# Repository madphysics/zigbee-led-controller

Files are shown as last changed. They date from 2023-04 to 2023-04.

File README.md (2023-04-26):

View this project on [CADLAB.io](https://cadlab.io/project/26827). 

# Zigbee LED Controller

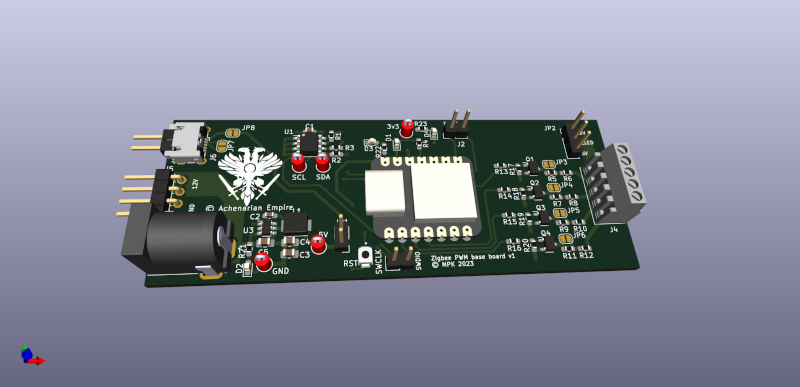
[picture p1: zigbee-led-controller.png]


A simple carrier card for driving some LEDs via PWM. Hosts an off the ZigBee module.

* Runs from 5V
* Derives 3v3 from 5V
* Has optional 12V rail for the PWM
* 4 channel, RGB+W low-side PWM

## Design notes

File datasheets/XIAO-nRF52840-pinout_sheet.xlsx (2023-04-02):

Pin | Name | Function | Description | Recommended usage | Seeed Studio XIAO nRF52840 pin definitions and functions |  |  |  | BOOT
A8 | P0.31 AIN7 | Digital I/O Analog input | General purpose I/O Analog input | Standard drive, low frequency I/O only |  |  |  |  | JTAG/SWD
A10 | P0.29 AIN5 | Digital I/O Analog input | General purpose I/O Analog input | Standard drive, low frequency I/O only | A3 | D3 |  |  | UART
A12 | P0.02 AIN0 | Digital I/O Analog input | General purpose I/O Analog input | Standard drive, low frequency I/O only | A0 | D0 |  |  | SPI
A14 | P1.15 | Digital I/O | General purpose I/O | Standard drive, low frequency I/O only |  | D10 | MOSI |  | ALL PWM
A16 | P1.13 | Digital I/O | General purpose I/O | Standard drive, low frequency I/O only |  | D8 | SCK |  | USB
A18 | DEC2 | Power | 1.3 V regulator supply decoupling |  |  |  |  |  | Analog
A20 | P1.10 | Digital I/O | General purpose I/O | Standard drive, low frequency I/O only |  |  |  |  | IIC
A22 | VDD | Power | Power supply |  |  |  |  |  | Digital
A23 | XC2 | Analog input | Connection for 32 MHz crystal |  |  |  |  |  | GPIO
B1 | VDD | Power | Power supply |  |  |  |  |  | QTouch
B3 | DCC | Power | DC/DC converter output |  |  |  |  |  | LED
B5 | DEC4 | Power | 1.3 V regulator supply decoupling | Must be connected to DEC6 (pin E24)
B7 | VSS | Power | Ground
B9 | P0.30 AIN6 | Digital I/O Analog input | General purpose I/O Analog input | Standard drive, low frequency I/O only |  | D13 | LED_GREEN
B11 | P0.28 AIN4 | Digital I/O Analog input | General purpose I/O Analog input | Standard drive, low frequency I/O only | A2 | D2
B13 | P0.03 | Digital I/O Analog input | General purpose I/O | Standard drive, low frequency I/O only | A1 | D1
B15 | P1.14 | Digital I/O | General purpose I/O | Standard drive, low frequency I/O only |  | D9 | MISO
B17 | P1.12 | Digital I/O | General purpose I/O | Standard drive, low frequency I/O only |  | D7 | PIN_SERIAL1_RX
B19 | P1.11 | Digital I/O | General purpose I/O | Standard drive, low frequency I/O only |  | D6 | PIN_SERIAL1_TX
B24 | XC1 | Analog input | Connection for 32 MHz crystal
C1 | DEC1 | Power | 1.1 V regulator supply decoupling
D2 | P0.00 XL1 | Digital I/O Analog input | General purpose I/O Connection for 32.768 kHz crystal
D23 | DEC3 | Power | Power supply, decoupling
E24 | DEC6 | Power | 1.3 V regulator supply decoupling | Must be connected to DEC4 (pin B5)
F2 | P0.01 XL2 | Digital I/O Analog input | General purpose I/O Connection for 32.768 kHz crystal
F23 | VSS_PA | Power | Ground (radio supply)
G1 | P0.26 | Digital I/O | General purpose I/O |  |  | D11 | LED_BUILTIN | LED_RED
H2 | P0.27 | Digital I/O | General purpose I/O
H23 | ANT | RF | Single-ended radio antenna connection | See Reference circuitry on page 588 for guidelines on how to ensure good RF performance
J1 | P0.04 AIN2 | Digital I/O Analog input | General purpose I/O Analog input |  | A4 | D4 | SDA
J24 | P0.10 NFC2 | Digital I/O NFC input | General purpose I/O NFC antenna connection | Standard drive, low frequency I/O only |  | D31 | NFC2 | VBAT
K2 | P0.05 AIN3 | Digital I/O Analog input | General purpose I/O Analog input |  | A5 | D5 | SCL
L1 | P0.06 | Digital I/O | General purpose I/O |  |  | D12 | LED_BLUE
L24 | P0.09 NFC1 | Digital I/O NFC input | General purpose I/O NFC antenna connection only | Standard drive, low frequency I/O only |  | D30 | NFC1
M2 | P0.07 TRACECLK | Digital I/O Trace clock | General purpose I/O Trace buffer clock
N1 | P0.08 | Digital I/O | General purpose I/O
N24 | DEC5 Not connected | Power | 1.3 V regulator supply decoupling for build codes Dxx and earlier. Not connected for build codes Fxx and later.
P2 | P1.08 | Digital I/O | General purpose I/O
P23 | P1.07 | Digital I/O | General purpose I/O | Standard drive, low frequency I/O only
R1 | P1.09 TRACEDATA3 | Digital I/O Trace data | General purpose I/O Trace buffer TRACEDATA[3]
R24 | P1.06 | Digital I/O | General purpose I/O | Standard drive, low frequency I/O only
T2 | P0.11 TRACEDATA2 | Digital I/O Trace data | General purpose I/O Trace buffer TRACEDATA[2]
T23 | P1.05 | Digital I/O | General purpose I/O | Standard drive, low frequency I/O only
U1 | P0.12 TRACEDATA1 | Digital I/O Trace data | General purpose I/O Trace buffer TRACEDATA[1]
U24 | P1.04 | Digital I/O | General purpose I/O | Standard drive, low frequency I/O only
V23 | P1.03 | Digital I/O | General purpose I/O | Standard drive, low frequency I/O only
W1 | VDD | Power | Power supply
W24 | P1.02 | Digital I/O | General purpose I/O | Standard drive, low frequency I/O only
Y2 | VDDH | Power | High voltage power supply
Y23 | P1.01 | Digital I/O | General purpose I/O | Standard drive, low frequency I/O only
AA24 | SWDCLK | Debug | Serial wire debug clock input for debug and programming
AB2 | DCCH | Power | DC/DC converter output
AC5 | DECUSB | Power | USB 3.3 V regulator supply decoupling
AC9 | P0.14 | Digital I/O | General purpose I/O |  |  | D14 | READ_BAT
AC11 | P0.16 | Digital I/O | General purpose I/O
AC13 | P0.18 nRESET | Digital I/O | General purpose I/O Configurable as pin RESET | QSPI/CSN
AC15 | P0.19 | Digital I/O | General purpose I/O | QSPI/SCK
AC17 | P0.21 | Digital I/O | General purpose I/O | QSPI |  | D24 | QSPI_SCK
AC19 | P0.23 | Digital I/O | General purpose I/O | QSPI |  | D29 | QSPI_SIO_3 HOLD
AC21 | P0.25 | Digital I/O | General purpose I/O |  |  | D25 | QSPI_CSN
AC24 | SWDIO | Debug | Serial wire debug I/O for debug and programming
AD2 | VBUS | Power | 5 V input for USB 3.3 V regulator
AD4 | D- | USB | USB D-
AD6 | D+ | USB | USB D+
AD8 | P0.13 | Digital I/O | General purpose I/O |  |  | D22 | BQ25100 HICHG
AD10 | P0.15 | Digital I/O | General purpose I/O
AD12 | P0.17 | Digital I/O | General purpose I/O |  |  | D23 | BQ25100 ~CHG
AD14 | VDD | Power | Power supply
AD16 | P0.20 | Digital I/O | General purpose I/O |  |  | D26 | QSPI_SIO_0 DI
AD18 | P0.22 | Digital I/O | General purpose I/O | QSPI |  | D28 | QSPI_SIO_2 WP
AD20 | P0.24 | Digital I/O | General purpose I/O |  |  | D27 | QSPI_SIO_1 DO
AD22 | P1.00 TRACEDATA0 | Digital I/O Trace data | General purpose I/O Trace buffer TRACEDATA[0] Serial wire output (SWO) | QSPI
AD23 | VDD | Power | Power supply
Die pad | VSS | Power | Ground pad | Exposed die pad must be connected to ground (VSS) for proper device operation

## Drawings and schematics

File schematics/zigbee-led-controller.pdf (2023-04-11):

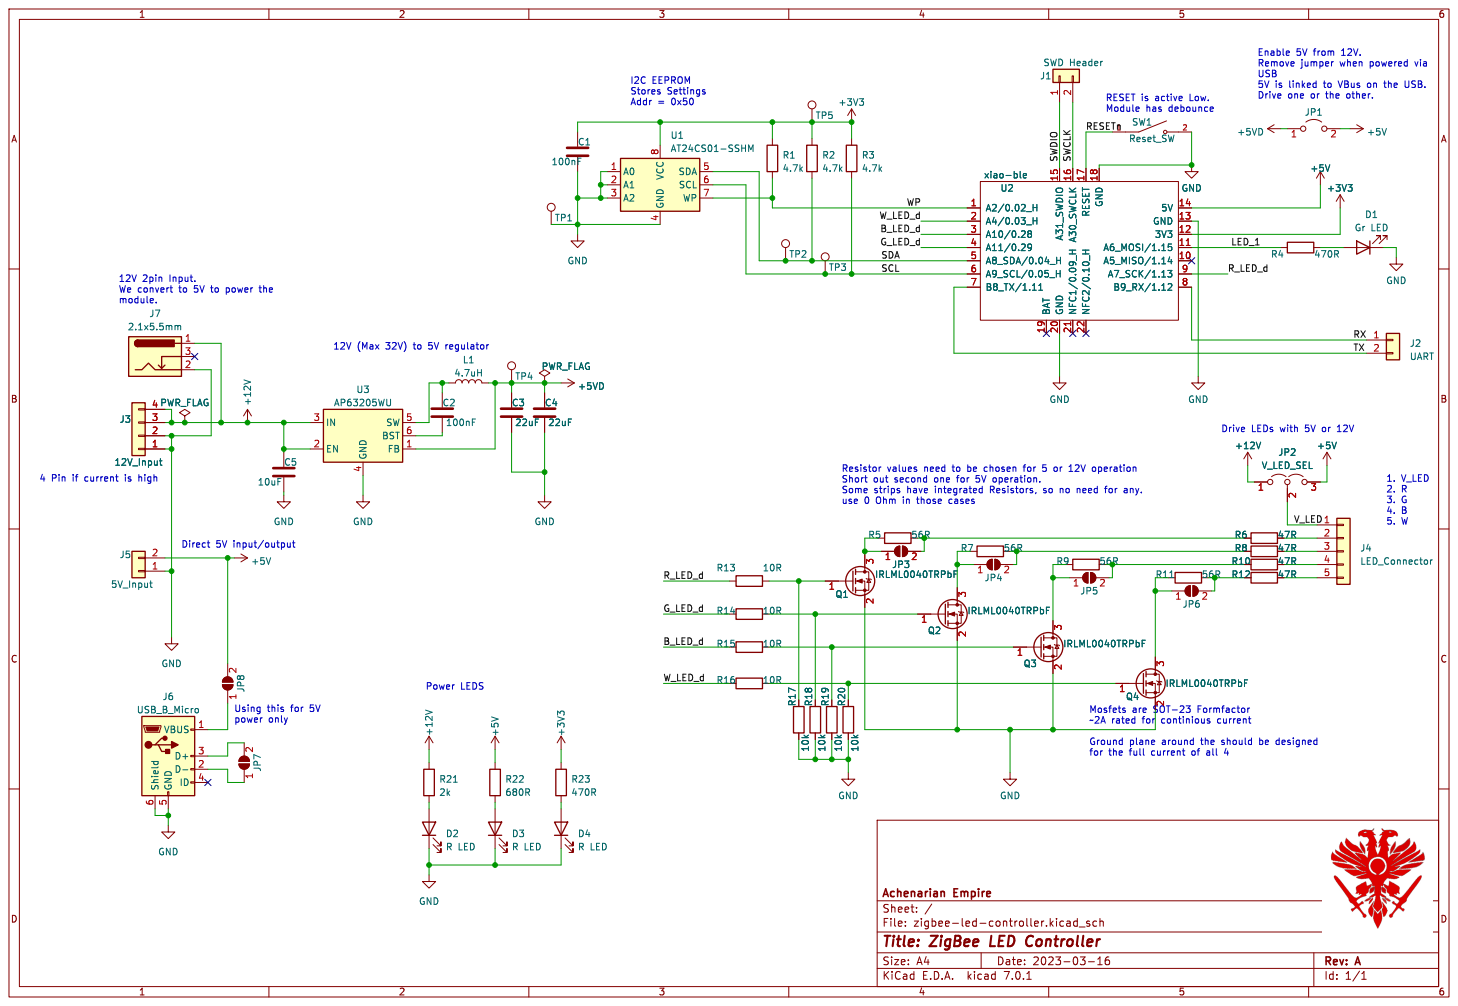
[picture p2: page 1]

Enable 5V from 12V. Remove jumper when powered via USB

4 SDA 5 SCL 6 WP 7 VCC

12V 2pin Input. We convert to 5V to power the module.
10uF GND

for the full current of all 4 Power LEDS Using this for 5V

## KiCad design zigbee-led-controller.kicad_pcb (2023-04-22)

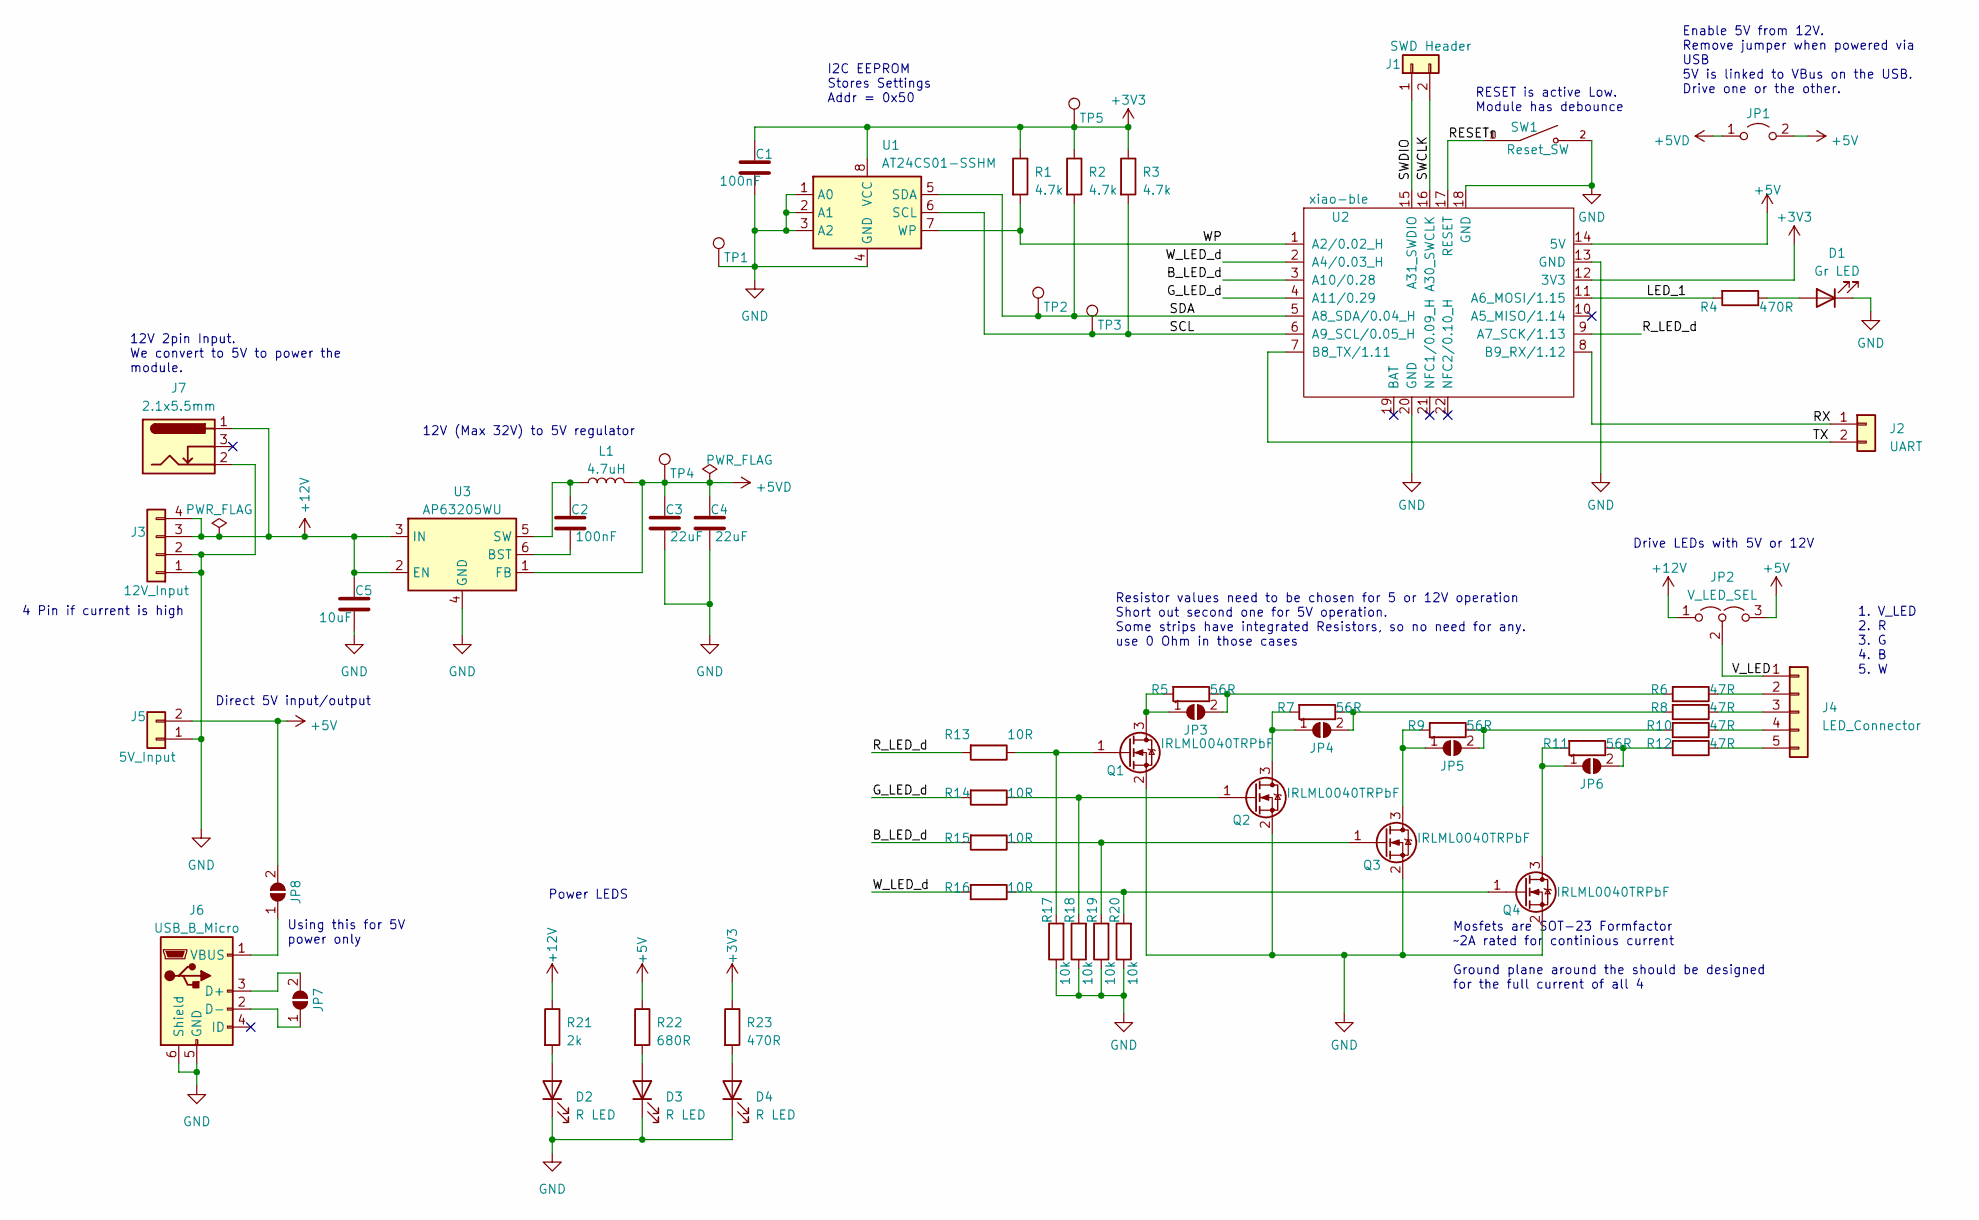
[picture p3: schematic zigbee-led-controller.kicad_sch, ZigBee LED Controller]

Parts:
C1, C2: 100nF; C_0603_1608Metric_Pad1.08x0.95mm_HandSolder
C3, C4: 22uF; C_0805_2012Metric_Pad1.18x1.45mm_HandSolder
C5: 10uF; C_0805_2012Metric_Pad1.18x1.45mm_HandSolder
D1: Gr LED; LED_0603_1608Metric_Pad1.05x0.95mm_HandSolder
D2, D3, D4: R LED; LED_0603_1608Metric_Pad1.05x0.95mm_HandSolder
J1: SWD Header; PinHeader_1x02_P2.54mm_Vertical
J2: UART; PinHeader_1x02_P2.54mm_Vertical
J3: 12V_Input; PinHeader_1x04_P2.54mm_Horizontal
J4: LED_Connector; PinHeader_1x05_P2.54mm_Vertical
J5: 5V_Input; PinHeader_1x02_P2.54mm_Horizontal
J6: USB_B_Micro; USB_Micro-B_Wuerth_629105150521
J7: 2.1x5.5mm; GRAVITECH_CON-SOCJ-2155
JP1: Jumper_2_Open; PinHeader_1x02_P2.54mm_Vertical
JP2: V_LED_SEL; PinHeader_1x03_P2.54mm_Vertical
JP3, JP4, JP5, JP6, JP7, JP8: Short; SolderJumper-2_P1.3mm_Open_RoundedPad1.0x1.5mm
L1: 4.7uH; L_Vishay_IHLP-1616
Q1, Q2, Q3, Q4: IRLML0040TRPbF; SOT-23-3
R1, R2, R3: 4.7k; R_0603_1608Metric_Pad0.98x0.95mm_HandSolder
R4, R23: 470R; R_0603_1608Metric_Pad0.98x0.95mm_HandSolder
R5, R7, R9, R11: 56R; R_0603_1608Metric_Pad0.98x0.95mm_HandSolder
R6, R8, R10, R12: 47R; R_0603_1608Metric_Pad0.98x0.95mm_HandSolder
R13, R14, R15, R16: 10R; R_0603_1608Metric_Pad0.98x0.95mm_HandSolder
R17, R18, R19, R20: 10k; R_0603_1608Metric_Pad0.98x0.95mm_HandSolder
R21: 2k; R_0603_1608Metric_Pad0.98x0.95mm_HandSolder
R22: 680R; R_0603_1608Metric_Pad0.98x0.95mm_HandSolder
SW1: Reset_SW; SW_B3U-1000P
TP1, TP2, TP3, TP4, TP5: TestPoint; TestPoint_Keystone_5000-5004_Miniature
U1: AT24CS01-SSHM; SOIC-8_3.9x4.9mm_P1.27mm
U2: xiao-ble; xiao-ble-smd-cutout
U3: AP63205WU; TSOT-23-6

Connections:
+3V3: C1.1, R1.1, R2.1, R3.1, R23.1, TP5.1, U1.8 (VCC), U2.12 (3V3); also elsewhere on the board
+5V: J5.2, JP1.2 (B), JP2.3 (B), JP8.2 (B), R22.1, U2.14 (5V)
+5VD: C3.1, C4.1, JP1.1 (A), L1.2, TP4.1, U3.1 (FB); also elsewhere on the board
+12V: C5.1, J3.3, J3.4, J7.1, JP2.1 (A), R21.1, U3.2 (EN), U3.3 (IN)
/B_LED_d: R15.2, U2.3 (A10/0.28)
/G_LED_d: R14.2, U2.4 (A11/0.29)
/LED_1: R4.2, U2.11 (A6_MOSI/1.15)
/RESETn: SW1.1, U2.17 (RESET); also elsewhere on the board
/RX: J2.1, U2.8 (B9_RX/1.12)
/R_LED_d: R13.2, U2.9 (A7_SCK/1.13)
/SCL: R3.2, TP3.1, U1.6 (SCL), U2.6 (A9_SCL/0.05_H); also elsewhere on the board
/SDA: R2.2, TP2.1, U1.5 (SDA), U2.5 (A8_SDA/0.04_H); also elsewhere on the board
/SWCLK: J1.2, U2.16 (A30_SWCLK)
/SWDIO: J1.1, U2.15 (A31_SWDIO)
/TX: J2.2, U2.7 (B8_TX/1.11)
/V_LED: J4.1, JP2.2 (C)
/WP: R1.2, U1.7 (WP), U2.1 (A2/0.02_H)
/W_LED_d: R16.2, U2.2 (A4/0.03_H)
GND: C1.2, C3.2, C4.2, C5.2, D1.1 (K), D2.1 (K), D3.1 (K), D4.1 (K), J3.1, J3.2, J5.1, J6.5 (GND), J6.6 (Shield), J7.2, Q1.2 (S), Q2.2 (S), Q3.2 (S), Q4.2 (S), R17.1, R18.1, R19.1, R20.1, SW1.2, TP1.1, U1.1 (A0), U1.2 (A1), U1.3 (A2), U1.4 (GND), U2.13 (GND), U2.18 (GND), U2.20 (GND), U3.4 (GND); also elsewhere on the board
unnamed: D1.2 (A), R4.1
unnamed: D2.2 (A), R21.2
unnamed: D3.2 (A), R22.2
unnamed: D4.2 (A), R23.2
unnamed: J4.2, R6.1
unnamed: J4.3, R8.1
unnamed: J4.4, R10.1
unnamed: J4.5, R12.1
unnamed: J6.3 (D+), JP7.2 (B)
unnamed: J6.2 (D-), JP7.1 (A)
unnamed: J6.1 (VBUS), JP8.1 (A)
unnamed: JP3.1 (A), Q1.3 (D), R5.2
unnamed: JP3.2 (B), R5.1, R6.2
unnamed: JP4.1 (A), Q2.3 (D), R7.2
unnamed: JP4.2 (B), R7.1, R8.2
unnamed: JP5.1 (A), Q3.3 (D), R9.2
unnamed: JP5.2 (B), R9.1, R10.2
unnamed: JP6.1 (A), Q4.3 (D), R11.2
unnamed: JP6.2 (B), R11.1, R12.2
unnamed: Q1.1 (G), R13.1, R17.2
unnamed: Q2.1 (G), R14.1, R18.2
unnamed: Q3.1 (G), R15.1, R19.2
unnamed: Q4.1 (G), R16.1, R20.2
unnamed: C2.2, U3.6 (BST)
unnamed: C2.1, L1.1, U3.5 (SW)

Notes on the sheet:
12V 2pin Input. We convert to 5V to power the module.
1. V_LED 2. R 3. G 4. B 5. W
I2C EEPROM Stores Settings Addr = 0x50
Power LEDS
Resistor values need to be chosen for 5 or 12V operation Short out second one for 5V operation. Some strips have integrated Resistors, so no need for any. use 0 Ohm in those cases
Enable 5V from 12V. Remove jumper when powered via USB 5V is linked to VBus on the USB. Drive one or the other.
Direct 5V input/output
12V (Max 32V) to 5V regulator
Using this for 5V power only
Mosfets are SOT-23 Formfactor ~2A rated for continious current Ground plane around the should be designed for the full current of all 4
Drive LEDs with 5V or 12V
4 Pin if current is high
RESET is active Low. Module has debounce

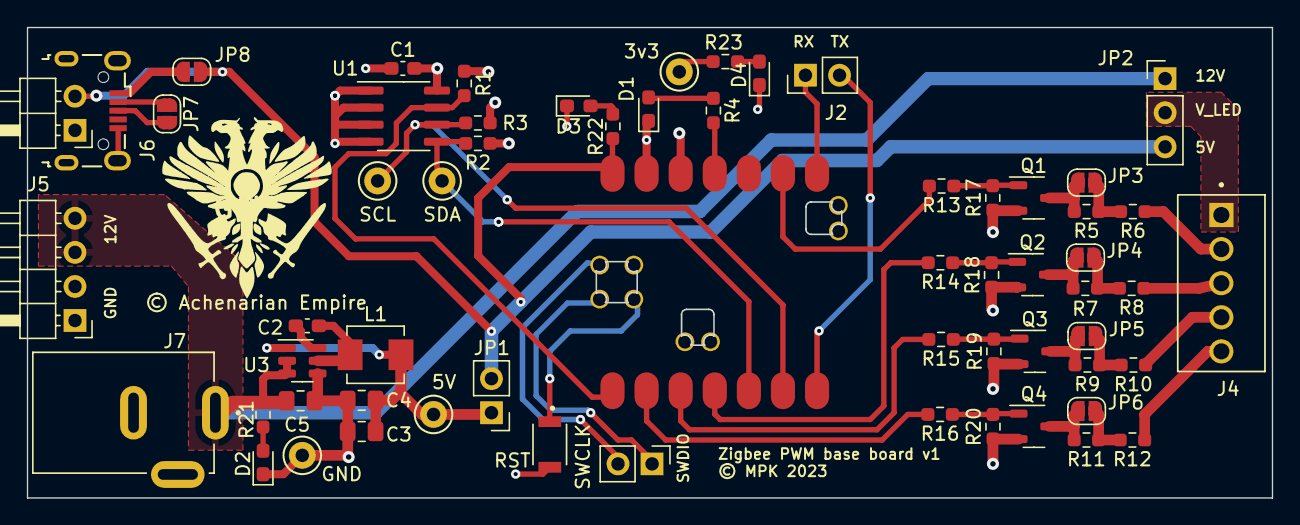
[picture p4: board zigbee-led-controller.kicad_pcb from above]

Board: 2 copper layers, 92.8 x 35.1 mm, 61 parts (0 on the bottom side), 44 nets.

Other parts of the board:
3v3, 5V: TestPoint; TestPoint_Keystone_5000-5004_Miniature
GND: TestPoint; TestPoint_Keystone_5000-5004_Miniature
RST: Reset_SW; SW_B3U-1000P
SCL: TestPoint; TestPoint_Keystone_5000-5004_Miniature
SDA: TestPoint; TestPoint_Keystone_5000-5004_Miniature

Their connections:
+3V3: 3v3.1; also elsewhere on the board
+5VD: 5V.1; also elsewhere on the board
/RESETn: RST.1; also elsewhere on the board
/SCL: SCL.1; also elsewhere on the board
/SDA: SDA.1; also elsewhere on the board
GND: GND.1, RST.2; also elsewhere on the board

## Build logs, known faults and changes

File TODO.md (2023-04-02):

## Things to be done

### Footprints

 * LED outpit connector

### Parts

 * LEDs
 * LED out put connector
 * PN for input connectors
 * FETs
 * USB connector

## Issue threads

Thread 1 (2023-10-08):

Issues from First build

madphysics, 2023-10-08:
Value for the current limiting resistors on the lowside of the LED driver need to be checked. Used a 10Ohm with a 5V test string, that gave around 150-200mA at 100% usage.

12V jack gnd pin is the wrong one, it should be the middle pin. Just jumper linked it under the board to test

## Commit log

2023-04-01 First pass at the schemaics
    [zigbee-led-controller.kicad_pcb, zigbee-led-controller.kicad_sch]
2023-04-01 PDF of first schematic
2023-04-02 Added GRAVITECH_CON-SOCJ-2155 footprint for the barrel connector.
    [zigbee-led-controller.kicad_sch]
2023-04-02 Datasheet/pins added
    [XIAO-nRF52840-pinout_sheet.xlsx]
2023-04-02 PCB Initial placement
    [zigbee-led-controller.kicad_pcb, zigbee-led-controller.kicad_sch]
2023-04-07 Routing done, first pass anyway.
    [zigbee-led-controller.kicad_pcb, zigbee-led-controller.kicad_sch]
2023-04-11 Updated some footprints and finalized layout. Added better output connector and rst switch
    [zigbee-led-controller.kicad_pcb, zigbee-led-controller.kicad_sch]
2023-04-11 Gerber outputs
    [zigbee-led-controller-B_Cu.gbr, zigbee-led-controller-B_Mask.gbr, zigbee-led-controller-B_Paste.gbr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]
2023-04-22 Updated, given to pcbway to quote
    [zigbee-led-controller-B_Cu.gbr, zigbee-led-controller-B_Mask.gbr, zigbee-led-controller-B_Paste.gbr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]

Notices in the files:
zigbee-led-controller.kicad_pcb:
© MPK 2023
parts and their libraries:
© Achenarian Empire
